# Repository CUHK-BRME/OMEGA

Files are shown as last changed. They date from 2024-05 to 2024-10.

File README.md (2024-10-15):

# OMEGA: Open-Source Multi-Mode Hopping Platform

**OMEGA** is a versatile, open-source hopping robot platform designed for research and educational purposes. It features a middle-sized robot equipped with an omnidirectional 3-RSR parallel leg, enabling seamless transitions between 1D, 2D, and 3D hopping modes. The platform is built using accessible manufacturing technologies, supporting both tethered and untethered experiments.

## Features:
- **Multi-mode hopping**: 1D, 2D, and 3D modes
- **3-RSR parallel leg**: Omnidirectional movement and force output
- **Accessible manufacturing**: 3D printing, water-jet cutting
- **Software**: For control learning and experiments

## Video Demonstration:
<video src="https://github.com/user-attachments/assets/fb11da87-3373-4812-8873-817871e5c72c" autoplay loop muted></video>

## Installation:

### 1. Hardware Setup
Follow the instructions in the `hardware` folder for setting up the physical components of OMEGA.

### 2. Software Setup
Ensure the following setup and requirements for software implementation:

- **Matlab Version**: 2018b (run as administrator)  

  **Required Add-ons**:
  - DSP System Toolbox
  - Embedded Coder
  - Instrument Control Toolbox
  - MATLAB Compiler
  - MATLAB Coder
  - Simulink Coder
  - Signal Processing Toolbox
  - Simscape
  - Simscape Electrical
  - Robotics System Toolbox
  - Aerospace Toolbox
  
- **Post Matlab Installation Add-ons** (requires non-institute network):
  - Simulink Support Package for Raspberry Pi Hardware
  - MATLAB Support for MinGW-w64 C/C++/Fortran Compiler (needed for compiling S-function builder)

- **Custom File Path Setup**:
  - Add `can_bus_multi` to the Matlab path.

- **Simulink Model Configuration Parameters**:
  - Set **Hardware Board** to **Raspberry Pi**.
  - Input the Raspberry Pi IP address and login credentials under **Target Hardware Resources**.
  - Enable **Run external mode in a background thread** under **External Mode**.

### 3. Running Experiments
Refer to the `software` folder for running 1D, 2D, and 3D hopping experiments.

## License:
OMEGA is licensed under the [MIT License](LICENSE).

---

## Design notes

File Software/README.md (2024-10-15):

# Software Instruction

### 1. Environment Setup

- **Matlab Version**: 2018b (set to always run as administrator)  

  **Required Add-ons**:
  - DSP System Toolbox
  - Embedded Coder
  - Instrument Control Toolbox
  - MATLAB Compiler
  - MATLAB Coder
  - Simulink Coder
  - Signal Processing Toolbox
  - Simscape
  - Simscape Electrical
  - Robotics System Toolbox
  - Aerospace Toolbox

- **Add-ons Needed After Matlab Installation** (require a non-institute network):
  - Simulink Support Package for Raspberry Pi Hardware
  - MATLAB Support for MinGW-w64 C/C++/Fortran Compiler (needed for compiling S-function builder)

- **Custom File Path Setup**:
  - Add `can_bus_multi` to the Matlab path.

- **Simulink Model Configuration Parameters**:
  - **Hardware Implementation**:
    - Set **Hardware Board** to **Raspberry Pi**.
  - **Hardware Board Settings**:
    - **Target Hardware Resources**:
      - Under **Board Parameters**, input the Raspberry Pi IP address and login credentials.
    - **External Mode**:
      - Enable **Run external mode in a background thread**.

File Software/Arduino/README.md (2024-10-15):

## Introduction
This path consist of Arduino support for the platform, instructions and code are included.

The Arduino Nano is responsible for collecting sensors' data, including IMU and encoder, and transmit said data to main computer (Raspberry Pi).

## Instruction
Upload the code to an Arduino Nano with the Arduino IDE.

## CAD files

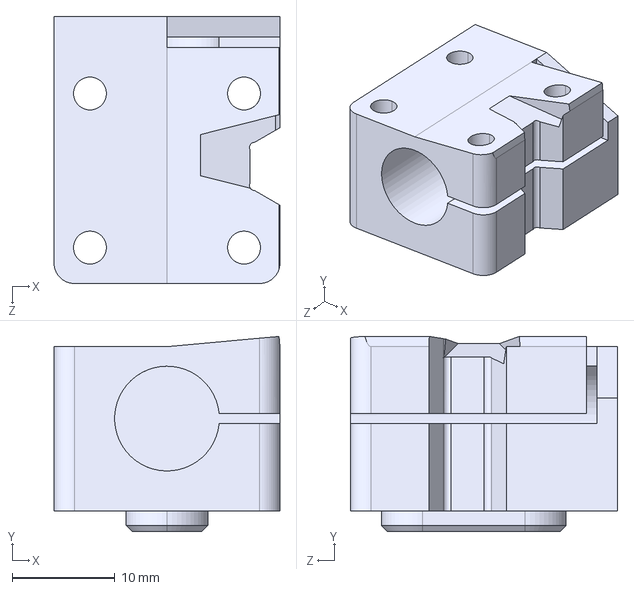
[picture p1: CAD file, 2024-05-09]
Hardware/CAD/leg motor mount v3 2 .STEP
22.0 x 19.0 x 26.0 mm

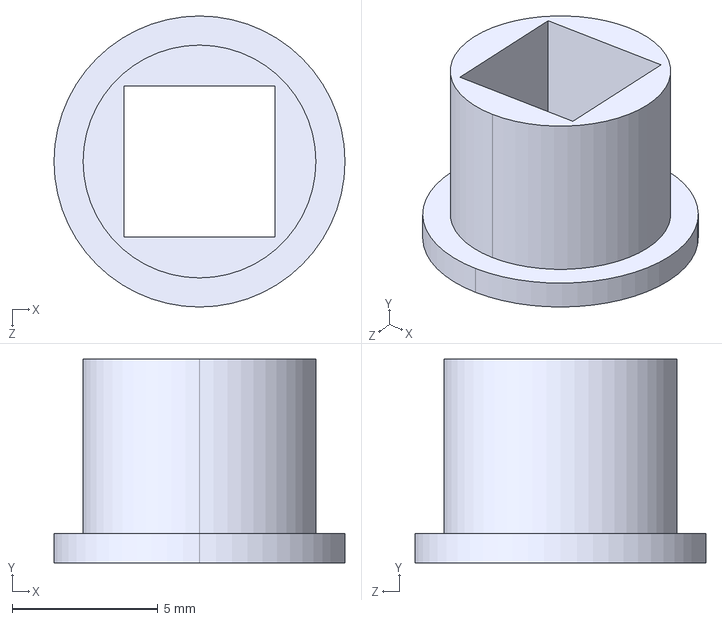
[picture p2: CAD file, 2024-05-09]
Hardware/CAD/foot2 v2.STEP
10.0 x 7.00 x 10.0 mm

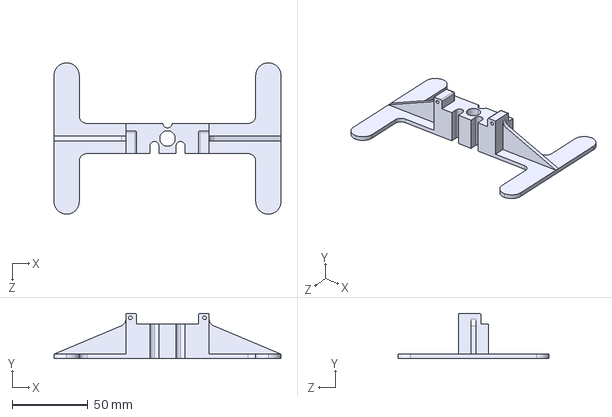
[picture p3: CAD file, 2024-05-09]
Hardware/CAD/vicon ball mount.STEP
150.0 x 30.0 x 100.0 mm

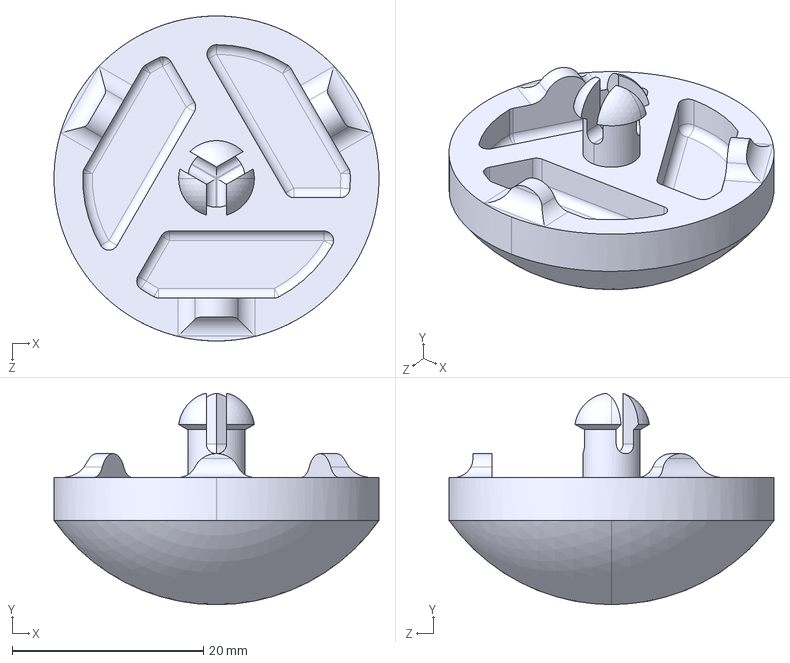
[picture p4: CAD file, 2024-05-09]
Hardware/CAD/foot3 v2.STEP
34.0 x 22.1 x 34.0 mm

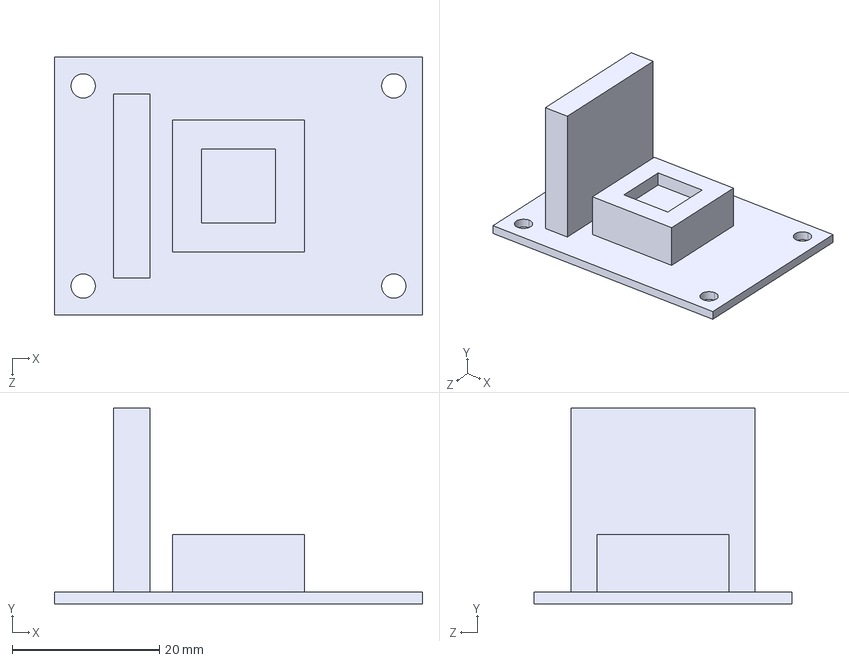
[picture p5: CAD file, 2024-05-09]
Hardware/CAD/LPMS-BE2-DK.STEP
50.0 x 26.6 x 35.0 mm

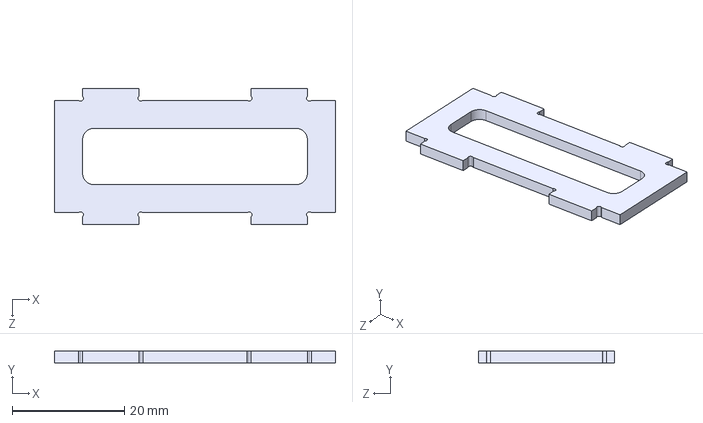
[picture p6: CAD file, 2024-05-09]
Hardware/CAD/CFplate-arm support v2.STEP
50.0 x 2.10 x 24.2 mm

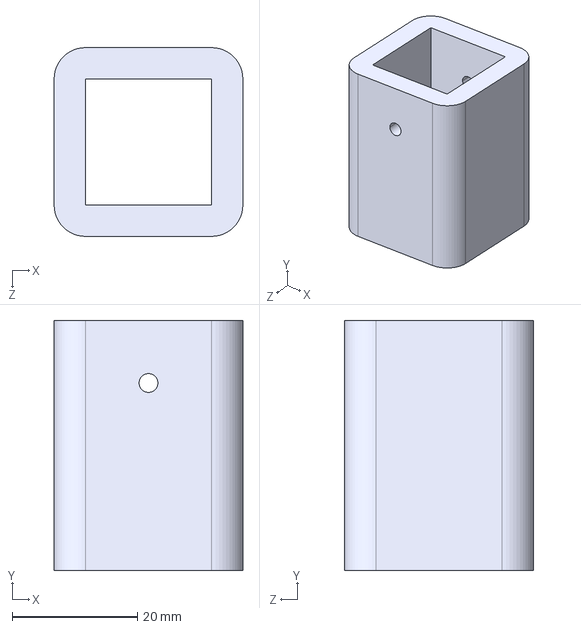
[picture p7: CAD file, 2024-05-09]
Hardware/CAD/temp arm cushion.STEP
30.2 x 40.0 x 30.2 mm

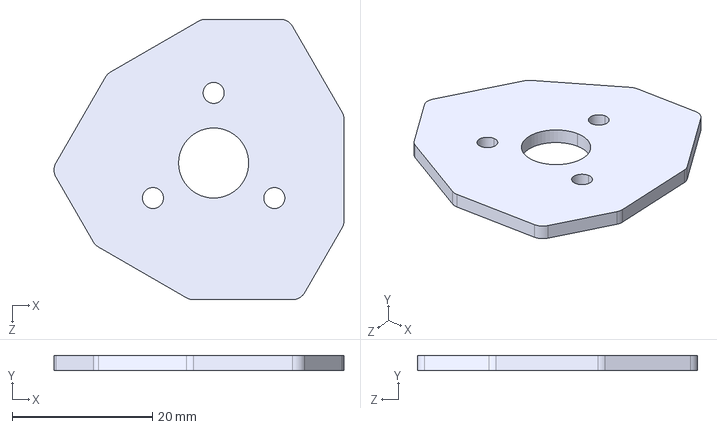
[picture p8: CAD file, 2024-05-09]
Hardware/CAD/hiptop stopper v2.STEP
41.4 x 2.10 x 40.0 mm

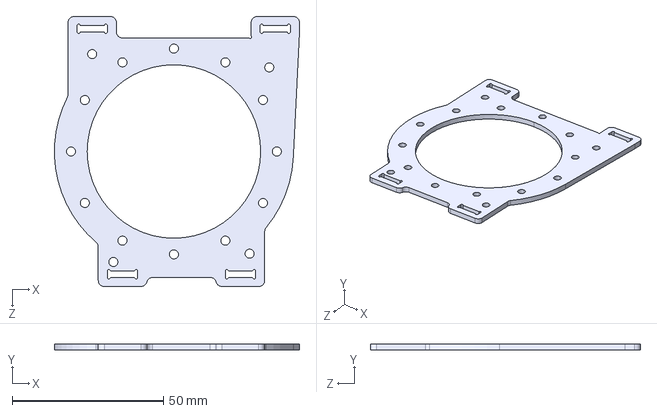
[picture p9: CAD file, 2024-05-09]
Hardware/CAD/CFplate-motor mount v2.STEP
81.0 x 2.10 x 89.2 mm

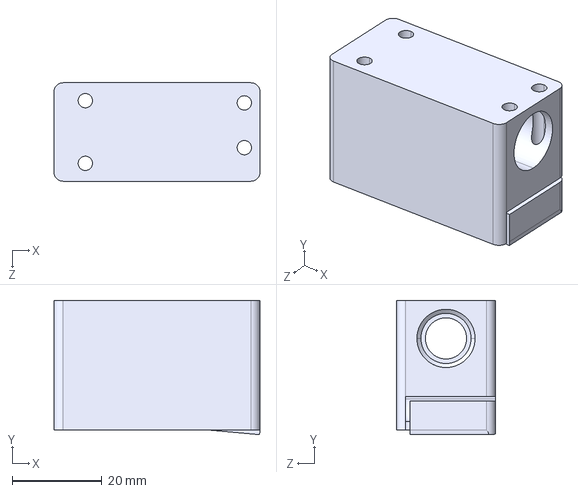
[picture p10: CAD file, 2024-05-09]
Hardware/CAD/drum knee mount.STEP
46.0 x 30.0 x 22.0 mm

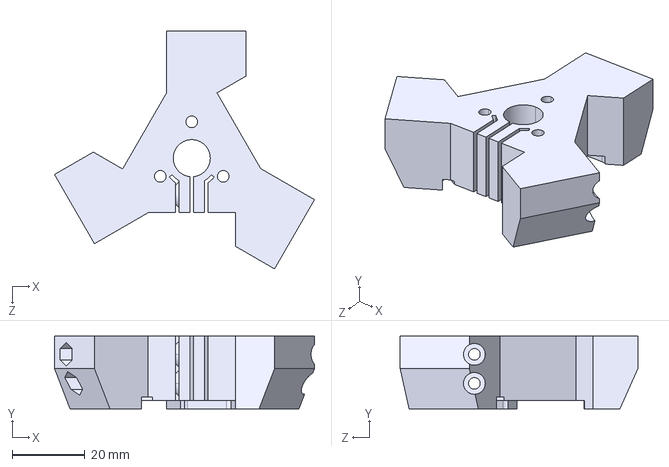
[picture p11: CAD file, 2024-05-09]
Hardware/CAD/handle lock v2.STEP
71.6 x 20.0 x 65.5 mm

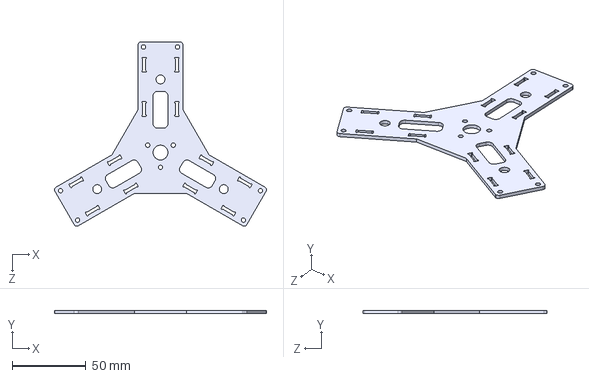
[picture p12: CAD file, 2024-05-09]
Hardware/CAD/CFplate-bodytop v2.STEP
143.5 x 2.10 x 124.8 mm

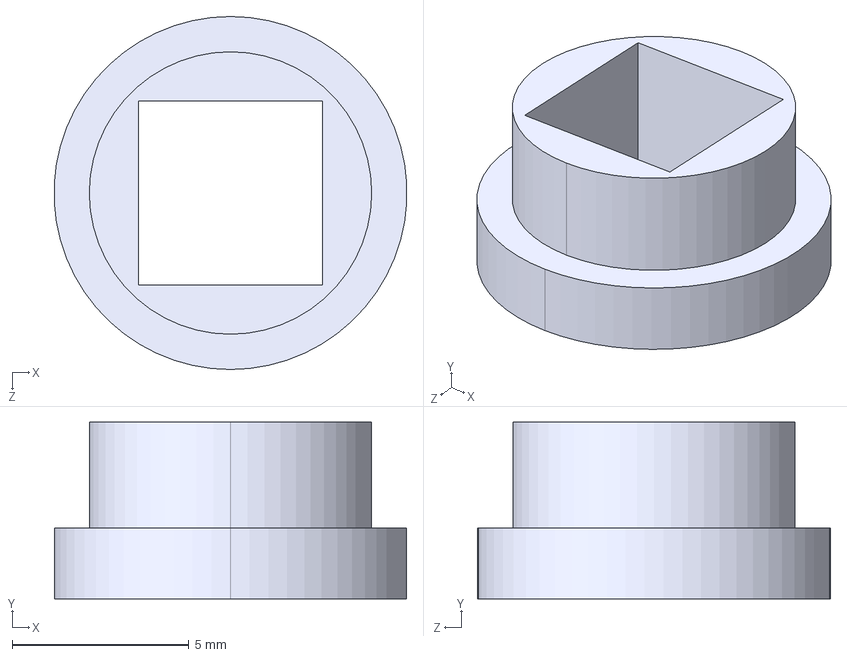
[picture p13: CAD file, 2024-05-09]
Hardware/CAD/knee cross bushing v2.STEP
9.99 x 5.00 x 10.0 mm

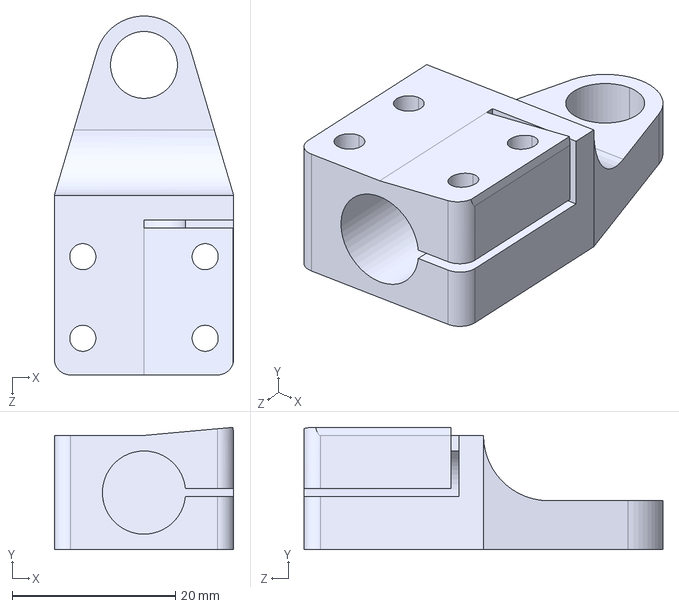
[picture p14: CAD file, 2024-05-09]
Hardware/CAD/leg foot mount1 v2.STEP
22.0 x 15.0 x 44.0 mm

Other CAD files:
Hardware/CAD/whole robot.STEP
Hardware/CAD/extension arm.STEP
Hardware/CAD/leg motor mount v3.STEP
Hardware/CAD/power hub.STEP
Hardware/CAD/685 bearing.STEP
Hardware/CAD/CFplate-hipbottom v2.STEP
Hardware/CAD/CFplate-hiptop v2.STEP
Hardware/CAD/CFplate-motor mount v2 3.STEP
Hardware/CAD/CFtube-103mm thigh.STEP
Hardware/CAD/CFtube-20x20x600mm arm.STEP
Hardware/CAD/CFtube-381mm drum.STEP
Hardware/CAD/ak60-6v1-1.stp
Hardware/CAD/arduino nano.STEP
Hardware/CAD/battery mount.STEP
Hardware/CAD/core electronics.STEP
Hardware/CAD/drum knee mount v2.STEP
Hardware/CAD/electronics mount.STEP
Hardware/CAD/foot v2.STEP
Hardware/CAD/foot1 v2.STEP
Hardware/CAD/handle.STEP
Hardware/CAD/hip bottom leg stopper v2.STEP
Hardware/CAD/hip v2.STEP
Hardware/CAD/knee cross v2.STEP
Hardware/CAD/knee plate v2.STEP
Hardware/CAD/knee shaft mount v2.STEP
Hardware/CAD/knee universal joint v2.STEP
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

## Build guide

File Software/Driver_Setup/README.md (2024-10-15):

## Instruction
1. Open the .exe to initiate bring up for the motor driver.
2. Plug the R-LINK to the USB port of the device using the .exe.
3. Plug the socket to the driver to be bring up.
4. Press "Connect" button.
5. Goto "MIT mode" tab.
6. Press "Debug" button.
7. Type 'exit'.
8. Type 'calibrate'.
9. Type 'setup'.
10. Follow the syntax format as instructed to change the CAN id of the driver.

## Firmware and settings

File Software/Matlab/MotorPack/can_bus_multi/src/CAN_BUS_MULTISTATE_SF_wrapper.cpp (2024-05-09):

/*
 * Include Files
 *
 */
#if defined(MATLAB_MEX_FILE)
#include "tmwtypes.h"
#include "simstruc_types.h"
#else
#include "rtwtypes.h"
#endif



/* %%%-SFUNWIZ_wrapper_includes_Changes_BEGIN --- EDIT HERE TO _END */
#ifndef MATLAB_MEX_FILE

#include <math.h>
#include <stdint.h>
#include <stdio.h>
#include <stdlib.h>
#include <string.h>
#include <unistd.h>
#include <net/if.h>
#include <sys/ioctl.h>
#include <sys/socket.h>
#include <linux/can.h>
#include <linux/can/raw.h>
#include <fcntl.h>
#include <sys/time.h>
#include "utility.h"
#include "utility.cpp"


#endif
/* %%%-SFUNWIZ_wrapper_includes_Changes_END --- EDIT HERE TO _BEGIN */
#define u_width 4
#define y_width 1

/*
 * Create external references here.  
 *
 */
/* %%%-SFUNWIZ_wrapper_externs_Changes_BEGIN --- EDIT HERE TO _END */
/* extern double func(double a); */
/* %%%-SFUNWIZ_wrapper_externs_Changes_END --- EDIT HERE TO _BEGIN */

/*
 * Start function
 *
 */
void CAN_BUS_MULTISTATE_SF_Start_wrapper(real_T *xD,
			void **pW,
			const uint8_T *device_num, const int_T p_width0,
			const uint8_T *can_port, const int_T p_width1,
			const uint8_T *safe_mode, const int_T p_width2)
{
/* %%%-SFUNWIZ_wrapper_Start_Changes_BEGIN --- EDIT HERE TO _END */
#ifndef MATLAB_MEX_FILE

pW[0] = new canChannel;
((canChannel *) pW[0]) -> comm_init( * can_port, * device_num);

// if(*can_port-1 == 0){
// system("sudo ip link set can0 type can bitrate 1000000");
// system("sudo ifconfig can0 up");
// system("sudo ifconfig can0 txqueuelen 65536");
// } else {
// system("sudo ip link set can1 type can bitrate 1000000");
// system("sudo ifconfig can1 up");
// system("sudo ifconfig can1 txqueuelen 65536");
// }
// 
// int ret;
// struct sockaddr_can addr;
// struct ifreq ifr;
// float zero_cmd[5] = {0, 0, 0, 0, 0};
// 
// //1.Create socket
// pW[0] = socket(PF_CAN, SOCK_RAW, CAN_RAW);
// if (pW[0] < 0) {
//     return;
// }
// 
// 
// //2.Specify can0 device
// if(*can_port-1 == 0){
//     strcpy(ifr.ifr_name, "can0");
// }
// else{
//     strcpy(ifr.ifr_name, "can1");
// }
// ret = ioctl(pW[0], SIOCGIFINDEX, &ifr);
// if (ret < 0) {
//     return;
// }
// 
// //3.Bind the socket to can0
// addr.can_family = AF_CAN;
// addr.can_ifindex = ifr.ifr_ifindex;
// ret = bind(pW[0], (struct sockaddr *)&addr, sizeof(addr));
// if (ret < 0) {
//     return;
// }
// 
// //4.Define receive rules
// struct can_filter rfilter[6];
// rfilter[0].can_id = 0x00;
// rfilter[1].can_id = 0x01;
// rfilter[2].can_id = 0x02;
// rfilter[3].can_id = 0x03;
// rfilter[4].can_id = 0x04;
// rfilter[5].can_id = 0x05;
// rfilter[0].can_mask = CAN_SFF_MASK;
// rfilter[1].can_mask = CAN_SFF_MASK;
// rfilter[2].can_mask = CAN_SFF_MASK;
// rfilter[3].can_mask = CAN_SFF_MASK;
// rfilter[4].can_mask = CAN_SFF_MASK;
// rfilter[5].can_mask = CAN_SFF_MASK;
// //rfilter[0].can_mask = 0xFFF;
// // setsockopt(pW[0], SOL_CAN_RAW, CAN_RAW_FILTER, NULL, 0);
// // setsockopt(pW[0], SOL_CAN_RAW, CAN_RAW_FILTER, &rfilter, sizeof(rfilter));
// setsockopt(pW[0], SOL_CAN_RAW, CAN_RAW_JOIN_FILTERS, &rfilter, sizeof(rfilter));
// 
// /*
// timeval tv;
// tv.tv_sec = 0;
// tv.tv_usec = 10000;
// setsockopt(pW[0], SOL_SOCKET, SO_SNDTIMEO, &tv, sizeof(tv));
// */
// 
// //5. set NON BLOCK
// fcntl(pW[0], F_SETFL, O_NONBLOCK);
// //fcntl(pW[0], F_GETFL, O_NONBLOCK);
// 
// //Initiallize
// struct can_frame tx_frame;
// tx_frame.can_dlc = 8;
// for(int i=0; i<*device_num; i++){ 
//     tx_frame.can_id = i + 1;  
//     ExitMotorMode(&tx_frame);
//     write(pW[0], &tx_frame, sizeof(struct can_frame));
// }
// 
// 
// //usleep(1000);

    
#endif
/* %%%-SFUNWIZ_wrapper_Start_Changes_END --- EDIT HERE TO _BEGIN */
}
/*
 * Output function
 *
 */
void CAN_BUS_MULTISTATE_SF_Outputs_wrapper(real32_T *m1_out,
			real32_T *m2_out,
			real32_T *m3_out,
			real_T *m4_out,
			const real_T *xD,
			void **pW,
			const uint8_T *device_num, const int_T p_width0,
			const uint8_T *can_port, const int_T p_width1,
			const uint8_T *safe_mode, const int_T p_width2)
{
/* %%%-SFUNWIZ_wrapper_Outputs_Changes_BEGIN --- EDIT HERE TO _END */
#ifndef MATLAB_MEX_FILE

 m4_out[0] = 0;
 m4_out[1] = 0;
 m4_out[2] = ((canChannel *) pW[0]) -> execution_timer(0);
((canChannel *) pW[0]) -> execution_timer(1);

((canChannel *) pW[0]) -> receive_process_frame();
for (int i=0; i<3; i++) {
    m1_out[i] = ((canChannel *) pW[0]) -> motor_state[1][i];
    m2_out[i] = ((canChannel *) pW[0]) -> motor_state[2][i];
    m3_out[i] = ((canChannel *) pW[0]) -> motor_state[3][i];
//     m4_out[i] = ((canChannel *) pW[0]) -> motor_state[4][i];
}

// int nbytes;
// struct can_frame rx_frame;
// 
// 
// /*
// //send cmd to devices
// if(*device_num > 0){
//     struct can_frame m1_tx_frame;
//     m1_tx_frame.can_id = 0x01;
//     m1_tx_frame.can_dlc = 8;
//     pack_cmd(&m1_tx_frame, m1_cmd);
//     write(pW[0], &m1_tx_frame, sizeof(struct can_frame)); 
// }
// 
// if(*device_num > 1){
//     struct can_frame m2_tx_frame;
//     m2_tx_frame.can_id = 0x02;
//     m2_tx_frame.can_dlc = 8;
//     pack_cmd(&m2_tx_frame, m2_cmd);
//     write(pW[0], &m2_tx_frame, sizeof(struct can_frame));
// }
// 
// if(*device_num > 2){
//     struct can_frame m3_tx_frame;
//     m3_tx_frame.can_id = 0x03;
//     m3_tx_frame.can_dlc = 8;
//     pack_cmd(&m3_tx_frame, m3_cmd);
//     write(pW[0], &m3_tx_frame, sizeof(struct can_frame));
// }
// 
// if(*device_num > 3){
//     struct can_frame m4_tx_frame;
//     m4_tx_frame.can_id = 0x04;
//     m4_tx_frame.can_dlc = 8;
//     pack_cmd(&m4_tx_frame, m4_cmd);
//     write(pW[0], &m4_tx_frame, sizeof(struct can_frame));
// }
// */
// 
// //read and unpack
// nbytes = 1;
// while(nbytes > 0){
//     nbytes = read(pW[0], &rx_frame, sizeof(rx_frame));
//     if(rx_frame.data[0] == 0x01)
//         unpack_reply(rx_frame, m1_out);
//     if(rx_frame.data[0] == 0x02)
//         unpack_reply(rx_frame, m2_out);
//     if(rx_frame.data[0] == 0x03)
//         unpack_reply(rx_frame, m3_out);
//     if(rx_frame.data[0] == 0x04)
//         unpack_reply(rx_frame, m4_out);
// }
// 
// //debug
// //debug[0] = *safe_mode;



#endif
/* %%%-SFUNWIZ_wrapper_Outputs_Changes_END --- EDIT HERE TO _BEGIN */
}

/*
 * Updates function
 *
 */
void CAN_BUS_MULTISTATE_SF_Update_wrapper(const uint8_T *mode,
			const real32_T *m1_cmd,
			const real32_T *m2_cmd,
			const real32_T *m3_cmd,
			const real32_T *m4_cmd,
			real32_T *m1_out,
			real32_T *m2_out,
			real32_T *m3_out,
			real_T *m4_out,
			real_T *xD,
			void **pW,
			const uint8_T *device_num, const int_T p_width0,
			const uint8_T *can_port, const int_T p_width1,
			const uint8_T *safe_mode, const int_T p_width2)
{
/* %%%-SFUNWIZ_wrapper_Update_Changes_BEGIN --- EDIT HERE TO _END */
/*
 * Code example
 *   xD[0] = u0[0];
 */

#ifndef MATLAB_MEX_FILE

// struct can_frame motor_tx_frame;
// motor_tx_frame.can_dlc = 8;
// float zero_cmd[5] = {0, 0, 0, 0, 0};

if(*safe_mode == 0){
    xD[4] = 1;
}

for(int i=0; i<*device_num; i++){
//     motor_tx_frame.can_id = i + 1;
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

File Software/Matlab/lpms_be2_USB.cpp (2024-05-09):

//reference https://lp-research.atlassian.net/wiki/spaces/LKB/pages/1941864458/LPMS3+Command+List

//LPBus packet format
//little endian 8N1 Uart
// 1st byte 0x3a
// 2nd - 3rd bytes uint16 device ID(default 1)
// 4th - 5th bytes uint16 command ID
// 6th - 7th bytes uint16 number of bytes for command parameters x
// 8th - 7+x bytes command parameters
// 7+x+1 - 7+x+2 checksum uint16 sum of 2nd to 7+x bytes
// 7+x+3 0x0d
// 7+x+4 0x0a
// SOURCE: https://blog.mbedded.ninja/programming/operating-systems/linux/linux-serial-ports-using-c-cpp/
#include <math.h>
#include <stdio.h>
#include <string.h>
#include <errno.h>
#include <fcntl.h>
#include <termios.h>
#include <unistd.h>
#include <sys/ioctl.h>
#include <iostream>
// additional libraries for wiringpi
#include <stdlib.h>
#include <stdint.h>
#include <stdarg.h>
#include <sys/types.h>
#include <sys/stat.h>

#include "lpms_be2_USB.h"

char receiveBuf[128];
char sendBuf[128];
int sendBufNum;
int receiveBufNum;
int receiveState;
float imu_time;
float imu_acc[3];
float imu_gyro[3];
float imu_quat[4];
unsigned int encoder_bytes_ang;
float encoder_ang;

char buffer[4096];
int receiveBufNum_log[4096];
int receiveState_log[4096];

typedef union {
  uint8_t u8vals[4];
  uint32_t u32val;
  float fval;
} data_decoder;

int comm_init_usb() {
    struct termios newtio;
    bzero(&newtio, sizeof(newtio)); /* clear struct for new port settings */
    /* BAUDRATE: Set bps rate. You could also use cfsetispeed and cfsetospeed.
        CS8     : 8n1 (8bit,no parity,1 stopbit)
        CLOCAL  : local connection, no modem contol
        CREAD   : enable receiving characters */
    newtio.c_cflag = SERIAL_BAUDRATE | CS8 | CLOCAL | CREAD;
    newtio.c_iflag = IGNPAR;

    /*  Raw output  */
    newtio.c_oflag = 0;

    newtio.c_cc[VTIME] = 0;
    newtio.c_cc[VMIN] = 1;

    /* ICANON  : enable canonical input
        disable all echo functionality, and don't send signals to calling program */
    newtio.c_lflag = 0;

    // Load the pin configuration
    /* Open modem device for reading and writing and not as controlling tty
    because we don't want to get killed if linenoise sends CTRL-C. */
    int fd = open("/dev/ttyAMA0", O_RDWR | O_NOCTTY | O_NONBLOCK);
    if (fd < 0) { perror("/dev/ttyAMA0"); exit(-1); }

    /* now clean the modem line and activate the settings for the port */
    tcflush(fd, TCIFLUSH);
    tcsetattr(fd, TCSANOW, &newtio);

    return fd;
}

int comm_init() { // from wiringpi
    struct termios options ;
    int status, fd ;

    if ((fd = open ("/dev/serial0", O_RDWR | O_NOCTTY | O_NDELAY | O_NONBLOCK)) == -1)
        return -1 ;

    fcntl (fd, F_SETFL, O_RDWR) ;

    // Get and modify current options:

    tcgetattr (fd, &options) ;

        cfmakeraw   (&options) ;
        cfsetispeed (&options, SERIAL_BAUDRATE) ;
        cfsetospeed (&options, SERIAL_BAUDRATE) ;

        options.c_cflag |= (CLOCAL | CREAD) ;
        options.c_cflag &= ~PARENB ;
        options.c_cflag &= ~CSTOPB ;
        options.c_cflag &= ~CSIZE ;
        options.c_cflag |= CS8 ;
        options.c_lflag &= ~(ICANON | ECHO | ECHOE | ISIG) ;
        options.c_oflag &= ~OPOST ;

        options.c_cc [VMIN]  =   0 ;
        options.c_cc [VTIME] = 100 ;	// Ten seconds (100 deciseconds)

    tcsetattr (fd, TCSANOW, &options) ;

    ioctl (fd, TIOCMGET, &status);

    status |= TIOCM_DTR ;
    status |= TIOCM_RTS ;

    ioctl (fd, TIOCMSET, &status);

    usleep (10000) ;	// 10mS

    return fd ;
}

int comm_init_uart1() { // from medium
    int serial_port = open("/dev/serial0", O_RDWR);
    struct termios tty;
    if(tcgetattr(serial_port, &tty) != 0) {
        printf("Error %i from tcgetattr: %s\n", errno, strerror(errno));
        return 1;
    }
    tty.c_cflag &= ~PARENB;
    tty.c_cflag &= ~CSTOPB;
    tty.c_cflag &= ~CSIZE;
    tty.c_cflag |= CS8;
    tty.c_cflag &= ~CRTSCTS;
    tty.c_cflag |= CREAD | CLOCAL;
    tty.c_lflag &= ~ICANON;
    tty.c_lflag &= ~ECHO;
    tty.c_lflag &= ~ECHOE;
    tty.c_lflag &= ~ECHONL;
    tty.c_lflag &= ~ISIG;
    tty.c_iflag &= ~(IXON | IXOFF | IXANY);
    tty.c_iflag &= ~(IGNBRK|BRKINT|PARMRK|ISTRIP|INLCR|IGNCR|ICRNL);
    tty.c_oflag &= ~OPOST;
    tty.c_oflag &= ~ONLCR;
    tty.c_cc[VTIME] = 10;
    tty.c_cc[VMIN] = 0;
    cfsetispeed(&tty, B115200);
    cfsetospeed(&tty, B115200);
    if (tcsetattr(serial_port, TCSANOW, &tty) != 0) {
        printf("Error %i from tcsetattr: %s\n", errno, strerror(errno));
        return 1;
    }
    return serial_port;
}

void imu_init(int fd) {
    imu_time = 0;
    for (int i=0;i<3;i++) {
        imu_acc[i] = 0;
        imu_gyro[i] = 0;
        imu_quat[i] = 0;
    }
    imu_quat[3] = 0;
    /*
    setGyroCommandMode(fd);
    sleep(1);
    tcflush(fd, TCIOFLUSH);
    setGyroStreamFreq(fd, LPMS_STREAM_FREQ_500HZ);
    sleep(1);
    setGyroDataEnable(fd, LPMS_RAW_ACC_OUTPUT_ENABLED | LPMS_RAW_GYR_OUTPUT_ENABLED);
    //setGyroDataEnable(fd, LPMS_QUAT_OUTPUT_ENABLED);
    sleep(1);
    setFilterMode(fd);
    sleep(1);
    setAccRange(fd);
    sleep(1);
    setGyroDataFast(fd);
    sleep(1);
    setGyroStreamMode(fd);
    */
    return;
}

void encoder_init() {
    encoder_bytes_ang = 0;
    encoder_ang = 0;
}
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
